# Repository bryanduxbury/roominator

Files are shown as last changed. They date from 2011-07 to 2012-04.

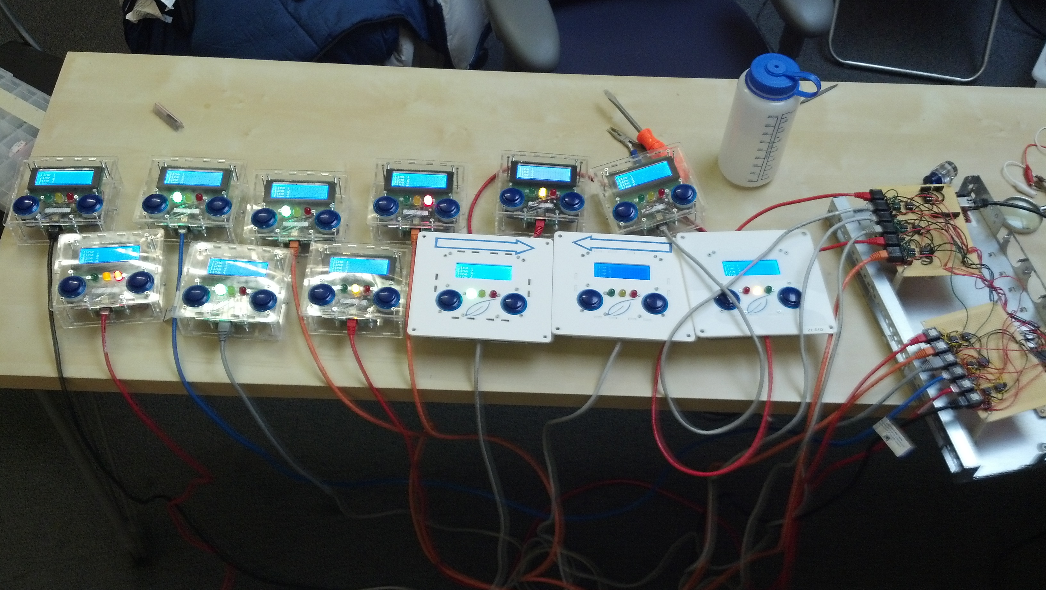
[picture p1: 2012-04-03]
photos/2012-01-26_09-58-28_648.jpg

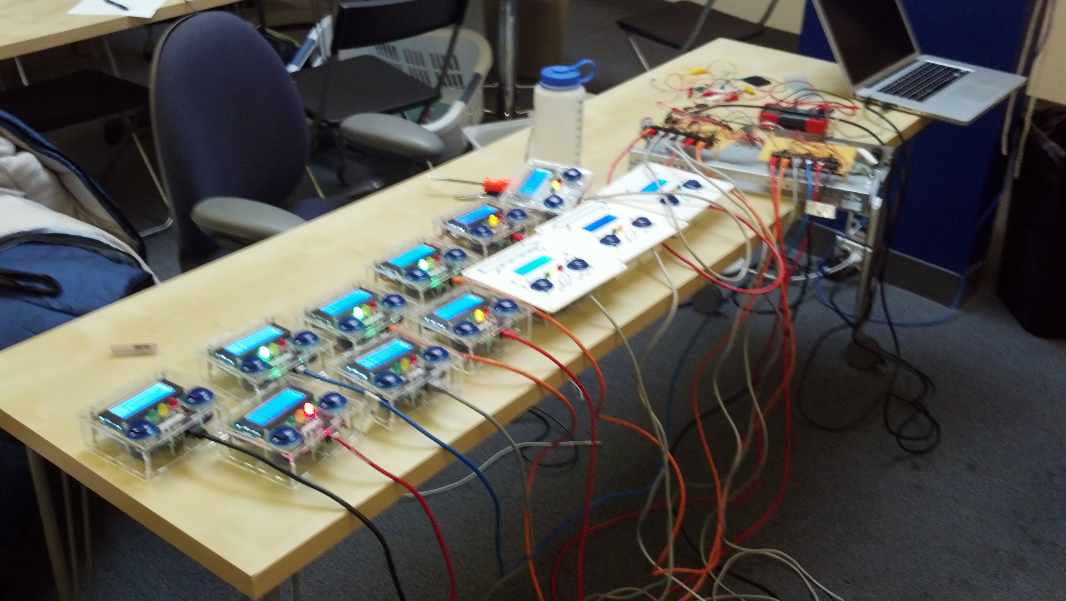
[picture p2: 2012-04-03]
photos/2012-01-26_09-58-02_43.jpg

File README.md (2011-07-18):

The Roominator is a project with the objective of producing DIY display terminals that can be posted outside of your offices' conference rooms and assist in scheduling and reservation.

The system is not a stand-alone scheduling solution - it's designed to complement an existing Google Calendar-backed room reservation setup. If you're like us here at Rapleaf, then you've probably gone so far as using Google Calendar for room reservation already. This is a pretty good system for the most part, but it has one major shortcoming: people who "just grab a room" when they need one rather than reserving. This is pretty natural behavior, especially when you've just picked up your phone and you need somewhere quiet to talk, so we want to make it easy to make ad-hoc reservations as well as avoid stealing rooms that are soon to be occupied.

The project consists of three components: an application server for interfacing with Google Calendar, a master control unit for coordinating with the displays, and one or more display units. 

Project goals:

 - Totally open-source hardware design and software
 - Keep system cost down: < $50 for displays, < $100 for the master
 - Easy to use and configure
 - Easy to expand with new displays

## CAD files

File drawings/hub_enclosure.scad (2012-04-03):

width = 19*25.4;
height = 3*25.4;
depth = 8 * 25.5;

material_thickness = 5;


module port_module() {
  color([128/255, 128/255, 128/255]) translate([0, 0, 0.8]) {
    difference() {
      cube(size=[50, 50, 1.6], center=true);
      for (angle = [0, 90, 180, 270]) {
        rotate([0, 0, angle]) translate([22, 22, 0]) {
          cylinder(r=1.6, h=10, center=true, $fn=16);
        }
      }
    }
  }

  translate([0, -22, 8.8]) {
    color([255/255, 255/255, 255/255]) {
      for (x = [-9, 9]) {
        translate([x, 0, 0]) {
          cube(size=[15.5, 20.9, 16], center=true);
        }
      }
    }
  }
}

module lcd_module() {
  color([128/255, 128/255, 128/255]) {
    difference() {
      cube(size=[100, 1.6, 60], center=true);
      for (x = [-1, 1]) {
        for (y = [-1, 1]) {
          translate([x*93/2, 0, y*55/2]) rotate([90, 0, 0]) cylinder(r=1.5, h=10, center=true);
        }
      }
    }
    translate([0, -1.6 - 9.9/2, 0]) {
      cube(size=[98, 9.9, 39.5], center=true);
    }
  }
}

module pwr_switch() {
  color([128/255, 128/255, 128/255]) {
    translate([0, -1, 0]) cube(size=[15, 2, 21], center=true);
    translate([0, 19.8/2, 0]) cube(size=[13, 19.8, 18.8], center=true);
    translate([0, -1 - 2.5, 0]) cube(size=[9.9, 5, 13], center=true);
  }
}

module pwr_plug() {
  color([128/255, 128/255, 128/255]) {
    cube(size=[20, 25, 25], center=true);
  }
}

module pwr_supply() {
  color([128/255, 128/255, 128/255]) {
    cube(size=[100, 50, 40], center=true);
  }
}

translate([0, 0, -height/2 + material_thickness / 2]) {
  cube([width, depth, material_thickness], center=true);
}

for (angle = [0, 180]) {
  rotate(a=[0,0,angle]) translate([width/2 - material_thickness/2, 0, 0]) {
    cube([material_thickness, depth, height], center=true);
  }
}

for (angle = [0, 180]) {
  rotate(a=[0,0,angle]) translate([0, depth/2 - material_thickness/2, 0]) {
    cube([width, material_thickness, height], center=true);
  }
}

translate([-width/2 + 10 + 25, -depth/2 + material_thickness + 25 + 2, -height/2 + material_thickness + 10]) {
  for (i = [0:5]) {
    translate([i * 52.5, 0, 0]) {
      port_module();
    }
  }
}

translate([-width/2 + 10 + 25 + 6 * 55 + 30, -depth/2 + material_thickness + 9.9+1.6, 0]) lcd_module();

translate([width/2 - material_thickness - 5 - 15/2, -depth/2, 0]) pwr_switch();

translate([width/2 - material_thickness - 10 - 12.5, depth/2 - 10, 0]) pwr_plug();

translate([width/2 - material_thickness - 10 - 25 - 10 - 50, depth/2 - material_thickness - 5 - 25, 0]) pwr_supply();

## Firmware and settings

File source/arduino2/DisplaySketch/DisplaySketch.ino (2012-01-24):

#include <Wire.h>
#include <LiquidCrystal.h>
#include <EEPROM.h>
#include <BounceButton.h>

#define L1 1
#define L2 2
#define L3 3
#define L4 4

char * line1 = "                    ";
char * line2 = "   waiting to sync  ";
char * line3 = "     with master    ";
char line4[21];

#define FLAGS 7

#define LED_NONE 0
#define LED_RED 1
#define LED_YELLOW 2
#define LED_GREEN 3

volatile int statusLed = LED_NONE;

unsigned int counter = 0;

LiquidCrystal lcd(13,12,11,10,9,8);

#define RED_PIN 4
#define YELLOW_PIN 5
#define GREEN_PIN 6

#define LBUTTON_PIN 2
#define RBUTTON_PIN 3
BounceButton lButton(LBUTTON_PIN);
BounceButton rButton(RBUTTON_PIN);

volatile unsigned int lButtonCounter = 0;
volatile unsigned int rButtonCounter = 0;

void setup() {
  strcpy(line4, line1);
  
//  Serial.begin(9600);
  lButton.initialize();
  rButton.initialize();
  
  pinMode(RED_PIN, OUTPUT);
  pinMode(YELLOW_PIN, OUTPUT);
  pinMode(GREEN_PIN, OUTPUT);
  digitalWrite(RED_PIN, HIGH);
  digitalWrite(YELLOW_PIN, HIGH);
  digitalWrite(GREEN_PIN, HIGH);

  lcd.begin(20,4);
  post();
  
  setOrResetDeviceId();
  
  Wire.begin(EEPROM.read(0));
//  Wire.begin(1);
  Wire.onRequest(requestHandler);
  Wire.onReceive(receiveHandler);
}

void post() {
  lcd.clear();
  lcd.setCursor(0,0);
  lcd.print("####################");
  lcd.setCursor(0,1);
  lcd.print("#     SELF TEST    #");
  lcd.setCursor(0,2);
  lcd.print("#                  #");
  lcd.setCursor(0,3);
  lcd.print("####################");

  digitalWrite(RED_PIN, LOW);
  delay(750);
  digitalWrite(YELLOW_PIN, LOW);
  delay(750);
  digitalWrite(GREEN_PIN, LOW);

  lcd.setCursor(0,2);
  lcd.print("#     COMPLETE!    #");

  delay(2000);

  digitalWrite(RED_PIN, HIGH);
  digitalWrite(YELLOW_PIN, HIGH);
  digitalWrite(GREEN_PIN, HIGH);
  lcd.clear();
}

void setOrResetDeviceId() {
  int deviceId = EEPROM.read(0);
  lcd.setCursor(0,0);

  if (deviceId == 0) {
    lcd.print("No Display ID set.");
    delay(2000);
    deviceId = getId();
  } else {
    long startMillis = millis();
    
    while(true) {
      long curMillis = millis();
      if (curMillis - startMillis > 6000) {
        break;
      }

      lcd.setCursor(0,0);
      lcd.print("Current ID: ");
      lcd.print(deviceId);
      lcd.setCursor(0,1);
      lcd.print("Press and hold both ");
      lcd.setCursor(0,2);
      lcd.print("buttons in the next ");
      lcd.setCursor(0,3);
      lcd.print((5000 - (curMillis-startMillis)) / 1000);
      lcd.print(" secs to change");
      
      
      bool res = lButton.check();
      bool can = rButton.check();
      if (res && can) {
        deviceId = getId();
        break;
      }
      delay(10);
    }
  }

  // store the device id back into the eeprom
  EEPROM.write(0, deviceId);

  // boot up the i2c interface with the provided device ID
  Wire.begin(deviceId);

  lcd.clear();
}

int getId() {
  lcd.clear();
  lcd.setCursor(0,0);
  lcd.print("Current value:");
  lcd.setCursor(0,3);
  lcd.print("Increment     Accept");
  while(lButton.check() || rButton.check()){delay(100);}

  int deviceId = 1;
  int i = 0;
  while (true) {
    i++;
    if (lButton.check()) {
      deviceId++;
      if (deviceId == 33) {
        deviceId = 1;
      }
      while(lButton.check()){}
    }
    if (rButton.check()) {
      break;
    }
    lcd.setCursor(0,1);
    lcd.print(deviceId);
    delay(10);
  }
  lcd.setCursor(0,2);
  lcd.print("      Accepted!     ");
  lcd.setCursor(0,3);
  lcd.print("                    ");
  delay(2000);
  
  return deviceId;
}

void loop() {
  if (lButton.check()) {
    lButtonCounter++;
  }

  if (rButton.check()) {
    rButtonCounter++;
  }
  
//  noInterrupts();
  lcd.setCursor(0, 0);
  lcd.print(line1);
  lcd.setCursor(0, 1);
  lcd.print(line2);
  lcd.setCursor(0, 2);
  lcd.print(line3);
  lcd.setCursor(0, 3);
  lcd.print(line4);
  
  // toggle all leds off
  digitalWrite(RED_PIN, HIGH);
  digitalWrite(YELLOW_PIN, HIGH);
  digitalWrite(GREEN_PIN, HIGH);
  
  // turn on the selected one, if any
  if (statusLed == LED_RED) {
    digitalWrite(RED_PIN, LOW);
  } else if (statusLed == LED_GREEN) {
    digitalWrite(GREEN_PIN, LOW);
  } else if (statusLed == LED_YELLOW) {
    digitalWrite(YELLOW_PIN, LOW);
  }

//  interrupts();

  delay(25);
}

void requestHandler() {
  Wire.write(lButtonCounter | (rButtonCounter << 4));
  lButtonCounter = 0;
  rButtonCounter = 0;
}

void receiveHandler(int numBytes) {
  int messageType = Wire.read();
//  Serial.print("Reading message type ");
//  Serial.print(messageType);

  switch(messageType) {
    case L1:
      readString(line1, numBytes - 1);
//      Serial.println(line1);
      break;
    case L2:
      readString(line2, numBytes - 1);
//      Serial.println(line2);
      break;
    case L3:
      readString(line3, numBytes - 1);
//      Serial.println(line3);
      break;
    case L4:
      readString(line4, numBytes - 1);
//      Serial.println(line4);
      break;      
    case FLAGS:
      statusLed = Wire.read();
//      Serial.println();
      break;
  }
}

void readString(char* dest, int len) {
  for (int i = 0; i < len; i++) {
    dest[i] = Wire.read();
  }
}

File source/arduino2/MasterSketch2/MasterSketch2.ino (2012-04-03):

#include <Wire.h>
#include "Messages.h"
#include <Ethernet.h>
#include <SPI.h>

char* failedLine1   = "       master       ";
char* failedLine2   = "  failed to connect ";
char* failedLine3   = "    to app server!  ";
char* failedLine4   = "                    ";

EthernetClient client;

byte mac[] = { 0xDE, 0xAD, 0xBE, 0xEF, 0xFE, 0xED };
//byte ip[] = { 10, 99, 33, 128 };
//byte gateway[] = { 10, 99, 33, 254 };
//byte mask[] = { 255, 255, 254, 0 }; 

byte ip[] = { 10, 0, 0, 2 };
byte gateway[] = { 10, 0, 0, 1 };
byte mask[] = { 255, 255, 255, 0 }; 

//byte appServerAddr[] = {10,99,32,69};
byte appServerAddr[] = {10,0,0,1};

void setup() {
  Ethernet.begin(mac, ip, gateway, mask);
  Wire.begin();
//  Serial.begin(9600);
  
  delay(1000);
}

void loop() {
  for (int i = 1; i < 16; i++) {
    Wire.requestFrom(i, 1);
    int statusCode = -1;
    while (Wire.available()) {
      if (statusCode == -1) statusCode = Wire.read();
      Wire.read();
    }
//    Serial.print("Node ");
//    Serial.print(i);
    if (statusCode == -1) {
      Serial.println(" is unreachable");
    } else {
//      Serial.print(" is online with status code: ");
//      Serial.println(statusCode);
      
      if (client.connect(appServerAddr, 80)) {
        client.print("GET /room/report?id=");
        client.print(i);
        client.print("&rsv=");
        client.print((statusCode & 0x0f) > 0 ? "1" : "0");
        client.print("&cancel=");
        client.print((statusCode & 0xf0) > 0 ? "1" : "0");
        client.println(" HTTP/1.0");
        client.println();
        
        // wait until *something* is available
        while (client.available() == 0) {delay(10);}
        
        // skip the header
        boolean inHeader = true;
        char lastChar = 0;
        char lastLastChar = 0;
        char lastLastLastChar = 0;
        while (client.available() > 0) {
          char c = client.read();
          if (c == '\n' && lastChar == '\r' && lastLastChar == '\n' && lastLastLastChar == '\r') {
            inHeader = false;
            break;
          }
          lastLastLastChar = lastLastChar;
          lastLastChar = lastChar;
          lastChar = c;
        }
        
        char blob[85];
        int idx = 0;
        while (client.available() > 0) {
          blob[idx++] = client.read();
        }
        if (idx != 85) {
//          Serial.println("Malformed message!");
          // todo: send malformed message notification
        } else {
          // send server's message to display
          sendString(i, 1, blob);
          sendString(i, 2, blob + 21);
          sendString(i, 3, blob + 42);
          sendString(i, 4, blob + 63);
          sendFlags(i, (int)(blob[84]));
        }
      } else {
//        Serial.println("Couldn't connect to app server.");
        sendString(i, 1, failedLine1);
        delay(10);
        sendString(i, 2, failedLine2);
        delay(10);
        sendString(i, 3, failedLine3);
        delay(10);
        sendString(i, 4, failedLine4);
        delay(10);
        sendFlags(i, 0);
      }
      client.stop();
    }
  }
  delay(100);
}

void sendString(int addr, int messageCode, char* str) {
  Wire.beginTransmission(addr);
  Wire.write(messageCode);
  Wire.write(str);
  Wire.endTransmission();
}

void sendFlags(int addr, int ledNum) {
  Wire.beginTransmission(addr);
  Wire.write(7);
  Wire.write(ledNum);
  Wire.endTransmission();
}

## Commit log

2011-07-18 adding schematics and board designs for the display
    [display.brd, display.sch]
2011-07-25 changes the display schematic
    [display.brd, display.sch]
2011-07-25 proof of concept i2c master/slave
2011-07-26 v1 test before running on board
2011-07-27 added a button library
2011-07-27 added button presses
2011-07-27 deals with button presses
2011-07-27 buttons working with slave
2011-07-28 did it burn it out?
    [MasterSketch.pde, SlaveSketch.pde]
2011-07-29 Cleaned up code, better serial print messages, still shipping bits correctly, but still have problem with slave reading them and printing to LCD
    [MasterSketch.pde]
2011-07-29 Super almost done prototype server. Latency sucks.
2011-07-29 Snapshot, working well, switching to new hardware
2011-07-29 fix bad junior config
    [SlaveSketch.pde]
2011-07-29 fix the led assignments for junior
    [SlaveSketch.pde]
2011-07-29 swap junior's buttons
2011-07-30 clean up the display schematic
    [display.brd, display.sch]
2011-07-30 design a much better board - very small
    [display.brd, display.sch]
2011-07-30 factor out a readFully method for reading packets from the Wire
2011-07-31 schematic/board for master hub board
    [master.sch, master_hub_board.brd, master_hub_board.sch]
2011-07-31 draft of the master support board. more work to be done to make it routable.
    [master.brd, master.sch]
2011-08-01 master main board permutations
    [master.brd]
2011-08-02 start of the LongWire library, for writing messages longer than 32 bytes over Wire
2011-08-03 redo the display board so no more vias
    [display.brd, display.sch]
2011-08-03 make the display board's holes bigger... and thus make the board bigger.
    [display.brd]
2011-08-03 fix up the board; new, smaller faceplate/box layout
    [display.brd, display.sch]
2011-08-04 switch back to memcpy based approach of deserialization; turns out that AVR is little-endian
2011-08-04 PoC that buttons work with display controller
2011-08-05 first attempt at corner bracket 3d model... going to have to redo both it and the faceplate though, since i wasn't accounting for the thickness of the faceplate material
    [3way_corner_bracket.skp, 3way_corner_bracket_2.skp]
2011-08-06 add svg version of box part drawings
    [3way_corner_bracket_2~.skp, 3way_corner_bracket_3.skp, 3way_corner_bracket_3~.skp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]
2011-08-07 updates to the display pcb - draft of producing a small accessory board for the status leds; adjust spacing on the faceplate (still a work in progress)
    [display.brd, display.sch]
2011-08-08 display board's looking good.
    [display.brd, display.sch]
2011-08-09 -trash the old arduino branch -get rid of the 'upcoming reservation' stuff -beginnings of alternating between primary/secondary message -default value for current/next reservations in room table
    [3way_corner_bracket_2slot.skp]
2011-08-09 -3 rotating messages now working as expected -start switching db schema towards something a little more in line with the new design
2011-08-09 add slotted back bottom bracket model
    [2way_back_bottom.skp, 2way_back_bottom~.skp, 3way_corner_bracket_2slot.skp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]
2011-08-09 add slotted back top bracket model (for mounting onto the wall)
    [top_back_brackets.skp, top_back_brackets~.skp]
2011-08-11 add new starts of stab at single-plate enclosure incl. new brackets
2011-08-11 ok, face part of single plate enclosure looks about right
2011-08-11 all of the sides are laid out, except for the back/mounting
2011-08-11 various uncommitted changes...
    [3way_corner_bracket_2slot.skp, 3way_corner_bracket_2slot~.skp]
2011-08-16 adjustments to enclosure svg to make sane-sized screws fit
2011-08-17 the back corner dimension was off on the sides by 3mm. fixed.
2011-08-17 other side's hole was off by a bit too
2011-08-21 finished redesign of enclosure: -added tab/groove elemnts to make the box more stable -simplified dimensions -mounting bracket is beefier, better positioned, better supported by box
2011-08-22 flip the faceplate so the leaf can be reverse-cut
2011-08-23 color the paths for cut ordering
2011-08-24 don't need these 3d models...
    [2way_back_bottom.skp, 2way_back_bottom~.skp, 3way_corner_bracket.skp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]
2011-08-24 ok, ok, let's try one of these tab-and-groove enclosures...
2011-08-24 move the button holes, place the faceplate screws
2011-08-25 basics of tabbed enclosure all set to go. might still want to add etching details.
2011-09-02 aha, found a bug - lcd pin 5 should be grounded, not lcd pin 4
    [display.brd, display.sch]
2011-09-02 flip the polarity so LED pins are set LOW to turn on
    [SlaveSketch.pde]
2011-09-02 verified board is set up correctly after bugfix to lcd1 header
    [display.brd, display.sch]
2011-09-02 adjustments to board
    [display.brd]
2011-09-07 reduce the depth of the sides by 3mm so that a 2in screw can reach from the front all the way to the back
2011-10-03 fix a weird routing bug in the roominator display board that was shorting out one of the lcd pins
    [display.brd]
2011-10-03 some changes to the tabbed enclosure svg (i can't remember what actually changed...)
2011-10-04 first pass (untested) at configurable i2c id
2011-10-06 fix issues in the bootup procedure
    [SlaveSketch.pde]
2011-10-06 fix a bug with the first press of the bounce button libs
2011-10-06 adjustments to master to read from EEPROM for device settings
2011-10-27 adjustments to board layout (v 1.1)
    [display.brd, display.sch, master.brd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]
2012-01-24 fix a small pointer sharing bug in the displays
    [DisplaySketch.ino]
2012-01-24 aborted attempt at converting MasterSketch to Arduino 1.0 (this sketch now supplanted by MasterSketch2
2012-01-24 eagle drawings for master hub segments board
    [master_hub.brd, master_hub.sch]
2012-01-25 Finishing the base implementation. Fully functional. Improvements: Display times in local time zone, edit/cancel events for all attendees not just rooms, display message immediately upon button push
2012-01-26 added display state to rotate long messages and allow pending status after button press
2012-04-03 another photo; scad file of enclosure concept
    [hub_enclosure.scad]
2012-04-03 some circuitry designed for the hub
    [port_segment.brd, port_segment.sch]
